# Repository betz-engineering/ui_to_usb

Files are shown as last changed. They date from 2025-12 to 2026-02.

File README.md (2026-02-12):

# ui_to_usb
Interface board to attach `ui_board_1u` to a PC or embedded computer over USB.
Based on a CH32V203 chip to handle the SPI interface and reading the encoder.

  * [Schematic](pics/ui_to_usb.pdf)
  * [Firmware](https://github.com/betz-engineering/ui_to_usb_firmware)

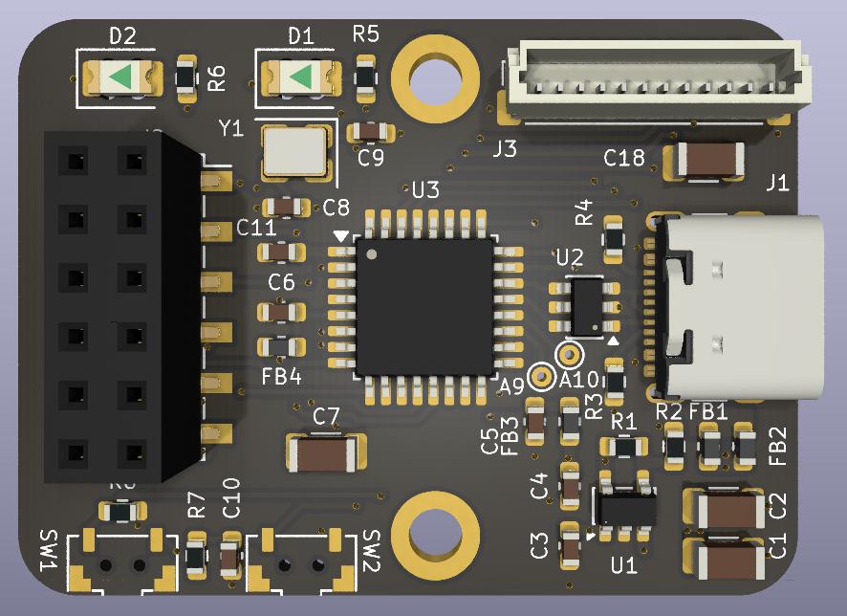
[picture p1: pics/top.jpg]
Bottom side


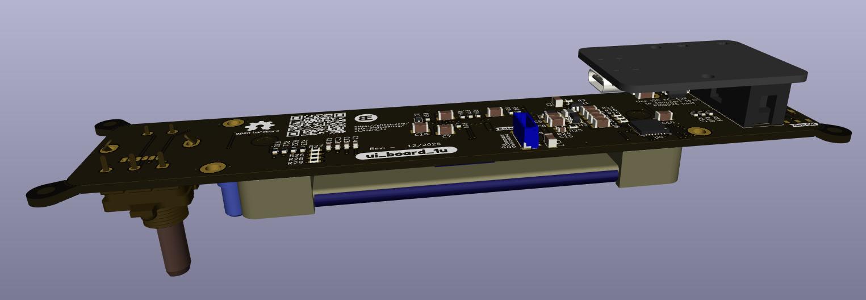
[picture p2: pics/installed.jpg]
Installed on ui_board_1u


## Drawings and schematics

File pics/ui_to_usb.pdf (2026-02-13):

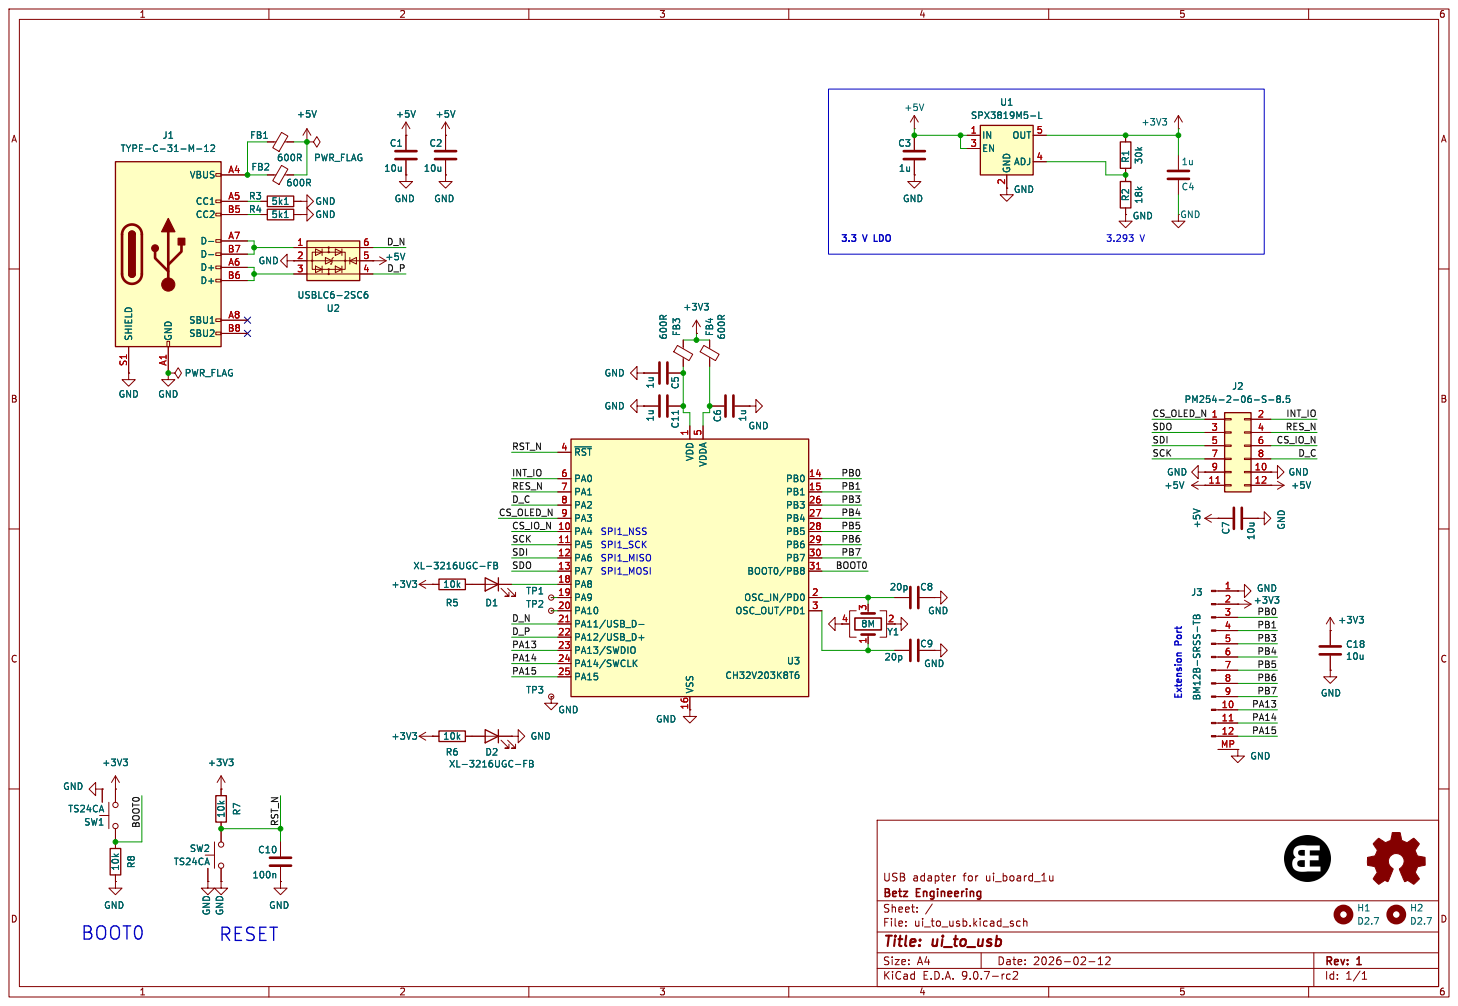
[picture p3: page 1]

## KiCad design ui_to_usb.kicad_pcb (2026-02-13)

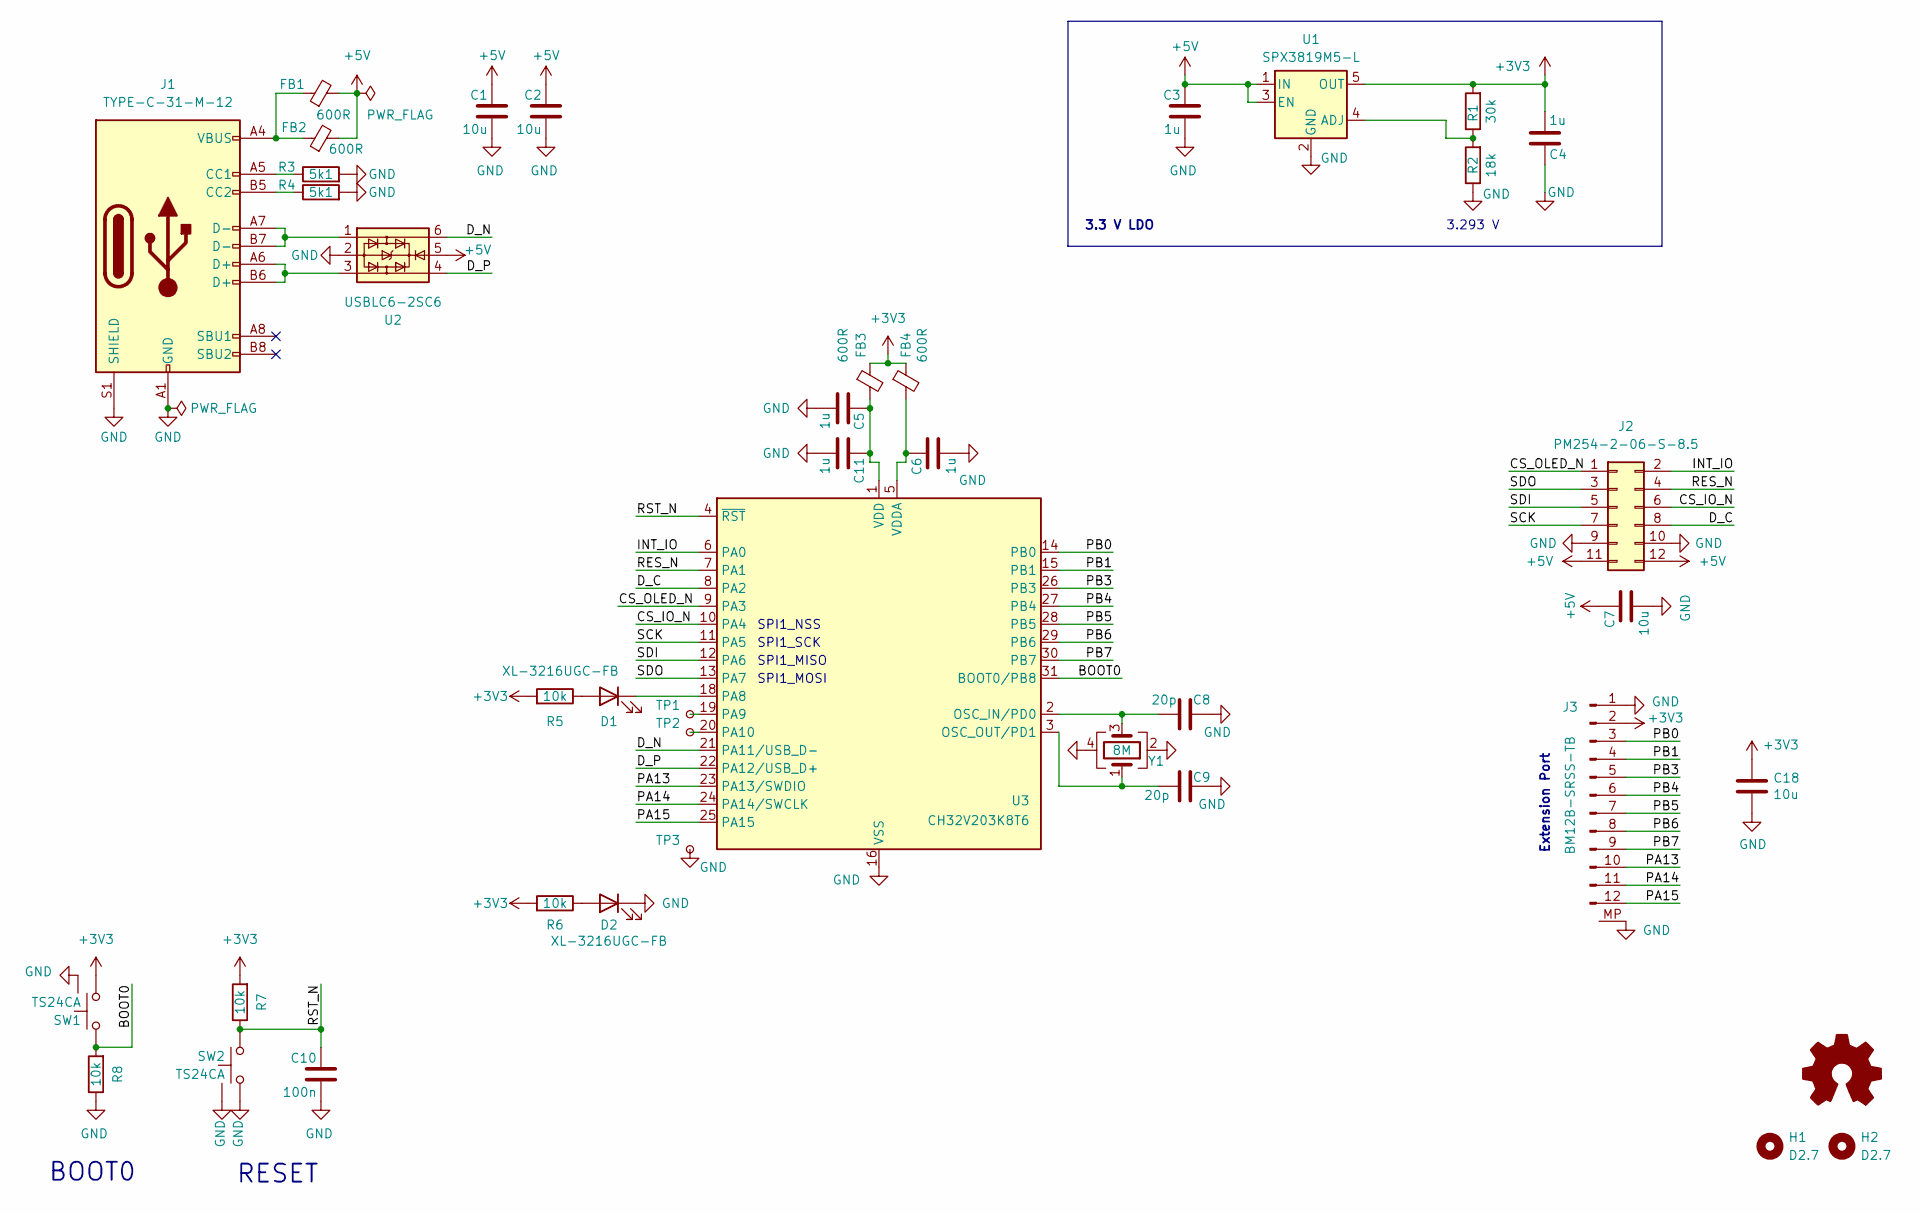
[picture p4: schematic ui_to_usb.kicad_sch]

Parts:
C1, C2, C7, C18: 10u; C_1206_3216Metric
C3, C4, C5, C6, C11: 1u; C_0603_1608Metric
C8, C9: 20p; C_0603_1608Metric
C10: 100n; C_0603_1608Metric
D1, D2: XL-3216UGC-FB; LED_1206_3216Metric_ReverseMount_Hole2.0x1.6mm
FB1, FB2, FB3, FB4: 600R; L_0603_1608Metric; JLCPCB Part # C19330
H1, H2: D2.7; MountingHole_2.7mm_M2.5_ISO7380_Pad
J1: TYPE-C-31-M-12; USB_C_Receptacle_GCT_USB4105-xx-A_16P_TopMnt_Horizontal
J2: PM254-2-06-S-8.5; PinSocket_2x06_P2.54mm_Vertical_SMD
J3: BM12B-SRSS-TB; JST_SH_BM12B-SRSS-TB_1x12-1MP_P1.00mm_Vertical; LCSC Part # C160393
R1: 30k; R_0603_1608Metric
R2: 18k; R_0603_1608Metric
R3, R4: 5k1; R_0603_1608Metric
R5, R6, R7, R8: 10k; R_0603_1608Metric
SW1, SW2: TS24CA
TP1: A9; TestPoint_Pad_D1.0mm
TP2: A10; TestPoint_Pad_D1.0mm
TP3: GND; TestPoint_Pad_D1.0mm
U1: SPX3819M5-L; SOT-23-5; LCSC Part # C9056
U2: USBLC6-2SC6; SOT-23-6
U3: CH32V203K8T6; LQFP-32_7x7mm_P0.8mm
Y1: 8M; Crystal_SMD_3225-4Pin_3.2x2.5mm; JLCPCB Part # C2682774

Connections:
+3V3: C4.1, C18.1, FB3.1, FB4.1, J3.2, R1.2, R5.2, R6.2, R7.2, SW1.1, U1.5 (OUT)
+5V: C1.2, C2.2, C3.2, C7.2, FB1.2, FB2.2, J2.11, J2.12, U1.1 (IN), U1.3 (EN), U2.5
/BOOT0: R8.2, SW1.2, U3.31 (BOOT0/PB8)
/CS_IO_N: J2.6, U3.10 (PA4)
/CS_OLED_N: J2.1, U3.9 (PA3)
/D_C: J2.8, U3.8 (PA2)
/D_N: U2.6, U3.21 (PA11/USB_D-)
/D_P: U2.4, U3.22 (PA12/USB_D+)
/INT_IO: J2.2, U3.6 (PA0)
/PA13: J3.10, U3.23 (PA13/SWDIO)
/PA14: J3.11, U3.24 (PA14/SWCLK)
/PA15: J3.12, U3.25 (PA15)
/PB0: J3.3, U3.14 (PB0)
/PB1: J3.4, U3.15 (PB1)
/PB3: J3.5, U3.26 (PB3)
/PB4: J3.6, U3.27 (PB4)
/PB5: J3.7, U3.28 (PB5)
/PB6: J3.8, U3.29 (PB6)
/PB7: J3.9, U3.30 (PB7)
/RES_N: J2.4, U3.7 (PA1)
/RST_N: C10.2, R7.1, SW2.2, U3.4 (~RST)
/SCK: J2.7, U3.11 (PA5)
/SDI: J2.5, U3.12 (PA6)
/SDO: J2.3, U3.13 (PA7)
GND: C1.1, C2.1, C3.1, C4.2, C5.1, C6.1, C7.1, C8.1, C9.1, C10.1, C11.1, C18.2, D2.1 (K), J1.A1 (GND), J1.A12 (GND), J1.B1 (GND), J1.B12 (GND), J1.S1 (SHIELD), J2.9, J2.10, J3.1, J3.MP, R2.1, R3.2, R4.2, R8.1, SW1.0, SW2.0, SW2.1, TP3.1, U1.2 (GND), U2.2, U3.16 (VSS), U3.32 (VSS), Y1.2, Y1.4
unnamed: D1.2 (A), R5.1
unnamed: D1.1 (K), U3.18 (PA8)
unnamed: D2.2 (A), R6.1
unnamed: FB1.1, FB2.1, J1.A4 (VBUS), J1.A9 (VBUS), J1.B4 (VBUS), J1.B9 (VBUS)
unnamed: J1.A5 (CC1), R3.1
unnamed: J1.B5 (CC2), R4.1
unnamed: J1.A6 (D+), J1.B6 (D+), U2.3
unnamed: J1.A7 (D-), J1.B7 (D-), U2.1
unnamed: R1.1, R2.2, U1.4 (ADJ)
unnamed: C8.2, U3.2 (OSC_IN/PD0), Y1.3
unnamed: C9.2, U3.3 (OSC_OUT/PD1), Y1.1
unnamed: TP1.1, U3.19 (PA9)
unnamed: TP2.1, U3.20 (PA10)
unnamed: C6.2, FB4.2, U3.5 (VDDA)
VDD: C5.2, C11.2, FB3.2, U3.1 (VDD), U3.17 (VDD)

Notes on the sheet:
SPI1_MISO
SPI1_SCK
3.293 V
Extension Port
RESET
BOOT0
SPI1_MOSI
SPI1_NSS
3.3 V LDO

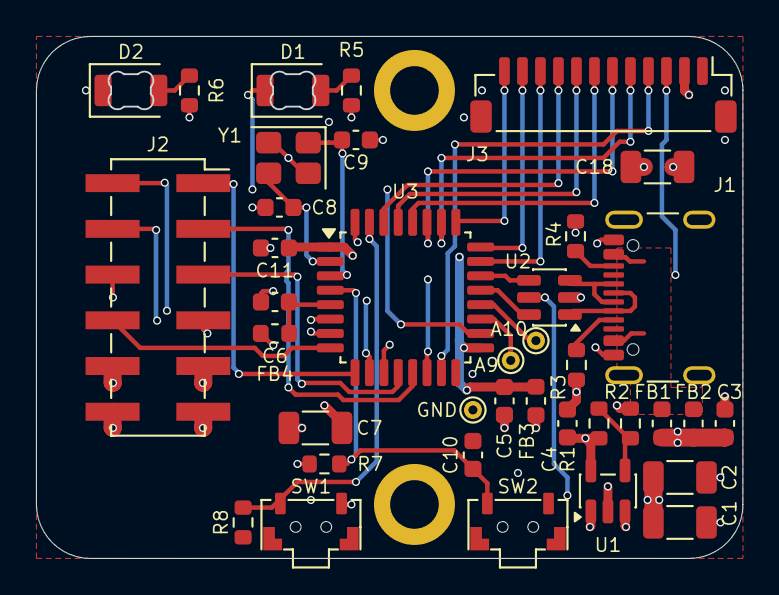
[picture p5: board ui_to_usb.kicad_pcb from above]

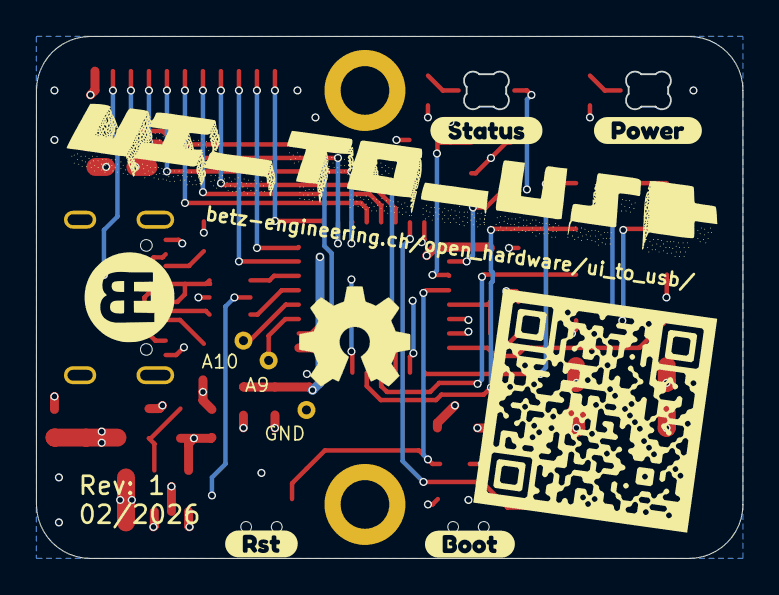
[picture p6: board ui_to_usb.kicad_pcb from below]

Board: 4 copper layers, 39.2 x 29.0 mm, 46 parts (6 on the bottom side), 40 nets.

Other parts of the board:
G1: LOGO
G2: OSHW-Logo2_9.8x8mm_SilkScreen
kibuzzard-698F164A: G***; kibuzzard-698F164A
kibuzzard-698F1642: G***; kibuzzard-698F1642
kibuzzard-6951C42C: G***; kibuzzard-6951C42C
kibuzzard-6951C425: G***; kibuzzard-6951C425

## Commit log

2025-12-28 initial commit
    * layout mostly completed
    * no DRC done yet
    [ui_to_usb.kicad_pcb, ui_to_usb.kicad_sch]
2025-12-28 add silkscreen
    fix all DRC errors
    [ui_to_usb.kicad_pcb, ui_to_usb.kicad_sch]
2025-12-29 move flash chip out of the way
    [ui_to_usb.kicad_pcb]
2025-12-29 bigger cut-out for LEDs. Add README and renders
    [ui_to_usb.kicad_pcb, ui_to_usb.kicad_sch]
2026-01-09 check sch and pcb before production, looks ready
    [ui_to_usb.kicad_pcb, ui_to_usb.kicad_sch]
2026-01-09 improve BOM, ordered rev -
    [ui_to_usb.kicad_pcb, ui_to_usb.kicad_sch]
2026-01-16 add ft232h.conf file
    * contains the serial of the last programmed device
2026-01-26 add CH32V305G (QFN28) symbol
    [ui_to_usb.kicad_sch]
2026-01-29 schematic progress
    [ui_to_usb.kicad_sch]
2026-01-31 switch to CH32V203
    as the V305 I've selected before doesn't have a BOOT0 pin
    [ui_to_usb.kicad_pcb, ui_to_usb.kicad_sch]
2026-01-31 schematic updates
    [ui_to_usb.kicad_sch]
2026-02-01 add extension port
    [ui_to_usb.kicad_pcb, ui_to_usb.kicad_sch]
2026-02-02 explore placement
    [ui_to_usb.kicad_pcb, ui_to_usb.kicad_sch]
2026-02-04 switch to 4 layers, all traces routed
    [ui_to_usb.kicad_pcb, ui_to_usb.kicad_sch]
2026-02-04 add tactile button footprint
    [ui_to_usb.kicad_pcb, ui_to_usb.kicad_sch]
2026-02-05 layout looks decent, 0 DRC errors
    [ui_to_usb.kicad_pcb]
2026-02-12 Layout looks decent. Ready to order.
    [ui_to_usb.kicad_pcb, ui_to_usb.kicad_sch]
2026-02-13 moved tactile buttons because of colission with shroud on ui_board_1u
    [ui_to_usb.kicad_pcb, ui_to_usb.kicad_sch]
2026-02-13 change 3V3 feedback resistor for more common values
    sent for production
    [ui_to_usb.kicad_pcb, ui_to_usb.kicad_sch]
